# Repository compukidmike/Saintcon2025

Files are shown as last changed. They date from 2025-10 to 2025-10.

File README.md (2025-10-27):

# Saintcon 2025 Badge

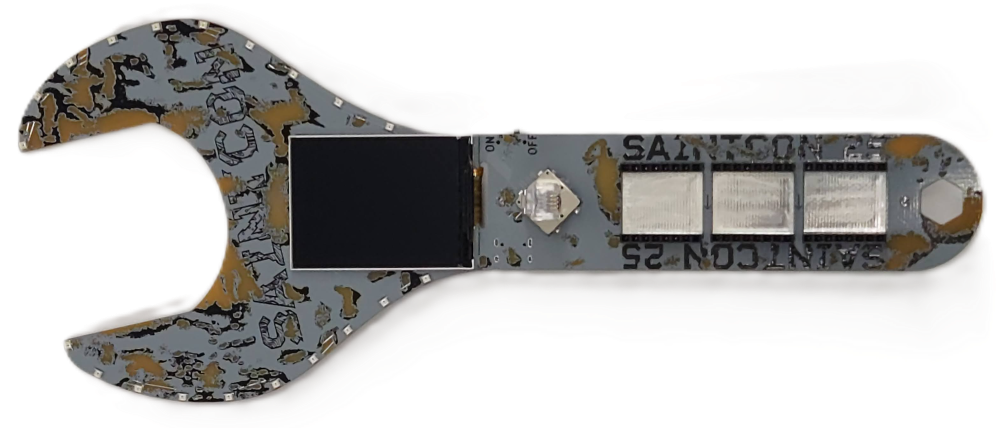
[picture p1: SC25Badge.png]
Saintcon2025 Badge


This year's badge is a comically oversized wrench. In technical terms it's a 50mm (~2in) wrench and the lanyard hole is a 10mm, naturally. It has an NFC tag embedded in the business end which is used for interacting with the badge game hardware. This, of course, involved turning Nuts which were NFC devices that would write one-time codes to the NFC tag in the badge. The badge would then check those codes in with the game server which would either award points or unlock game nodes.

The board files and firmware for the badges and the nuts is included here. If you have any questions or want more info about anything, please let me know!

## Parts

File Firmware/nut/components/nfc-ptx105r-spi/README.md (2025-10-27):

# PTX105R Arduino Library

This NFC library uses the **PTX105R non-OS IOT Reader SDK v7.2.0** for the **SPI** interface.

There are four examples to demonstrate the following functionality:
- Read NDEF message
- Write NDEF message to NDEF-formatted cards
- Emulate a Type 4 tag containing an NDEF message
- Run the SDK's reader demo application, which displays basic card information

Supported RF-technology types: A, B, F, V

Supported tag-protocol types: Type 2, 3, 4, 5

## Board Compatibility

- Arduino UNO R4 MINIMA
- Arduino UNO R4 WiFi

## Shield Compatibility

- WS004-NFCShield-PoCZ PTX105R Arduino Shield Rev A

## Getting Started

Please refer to the [User Manual](https://lpccs-docs.renesas.com/ntpg_apps/ptx105r_arduino_shield/spi/latest/tutorial/index.html) and [Product Page](https://www.renesas.com/en/products/wireless-connectivity/nfc/ptx105r-mid-power-multi-protocol-nfc-forum-compliant-reader/WS031-NFCShld-REFZ-PTX105R-Arduino-Shield-R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) for more information.

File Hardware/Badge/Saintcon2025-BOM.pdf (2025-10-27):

Saintcon2025 Final BOM

Reference | Qty | Value | Footprint
BT1 | 1 | Battery | Battery:BatteryHolder_MPD_BC12AAPC_2xAA
C1,C7,C10 | 3 | 0.1uF | Capacitor_SMD:C_0603_1608Metric
C2,C3,C5,C6,C8,C9,C11,C12,C14 | 9 | 10uF | Capacitor_SMD:C_0603_1608Metric
C4,C19 | 2 | 1uF | Capacitor_SMD:C_0603_1608Metric
C13 | 0 | DNP | Capacitor_SMD:C_0603_1608Metric
D1,D2,D3,D4,D5,D6,D7,D8,D9,D1 0,D11,D12,D13,D14,D15,D16,D17, D18,D19,D20 | 20 | WS2812B-2020 | LED_SMD:LED_WS2812B-2020_PLCC4_2.0x2.0mm
J1 | 1 | USB_C_Receptacle_USB2.0 | Connector_USB:USB_C_Receptacle_XKB_U262-16XN-4BVC11
L1 | 1 | L | Inductors:L_0806_2016
R1,R11 | 2 | 10k | Resistor_SMD:R_0603_1608Metric
R2,R3 | 2 | 5.1k | Resistor_SMD:R_0603_1608Metric
R4 | 1 | 10 | Resistor_SMD:R_0603_1608Metric
R5,R6 | 2 | 1.2k | Resistor_SMD:R_0603_1608Metric
R7,R8 | 2 | 4.7k | Resistor_SMD:R_0603_1608Metric
R9 | 1 | 365 | Resistor_SMD:R_0603_1608Metric
R10 | 1 | 1k | Resistor_SMD:R_0603_1608Metric
SW1 | 1 | SW_SPDT | C&KSlideSwitches:JS202011JAQN
SW2 | 1 | 4-WayW/switch | NavSwitchSMD:2425755-1
U1 | 1 | AZ1117-3.3 | Package_TO_SOT_SMD:SOT-89-3
U2 | 1 | LCD-2_0-ST7789 | LCD_Displays:LCD-2_0-ST7789V-22PIN
U3 | 1 | ATECC608B-SSHDA | Package_SO:SOIC-8_3.9x4.9mm_P1.27mm
U4 | 1 | ESP32-S3-WROOM-1 | Espressif:ESP32-S3-WROOM-1
U5 | 1 | XC9148G33DER-G | Package_USP:USP-6C
U6 | 1 | ST25DV04K-IER6S3 | Package_SO:SO-8_3.9x4.9mm_P1.27mm
U9 | 1 | A3910 | Package_DFN_QFN:DFN-8-1EP_2x2mm_P0.5mm_EP0.9x1.6mm
U10,U11,U13 | 3 | SAINTCON-Minibadge | minibadge_kicad:SAINTCON-Minibadge-Shiny-SmallHoles

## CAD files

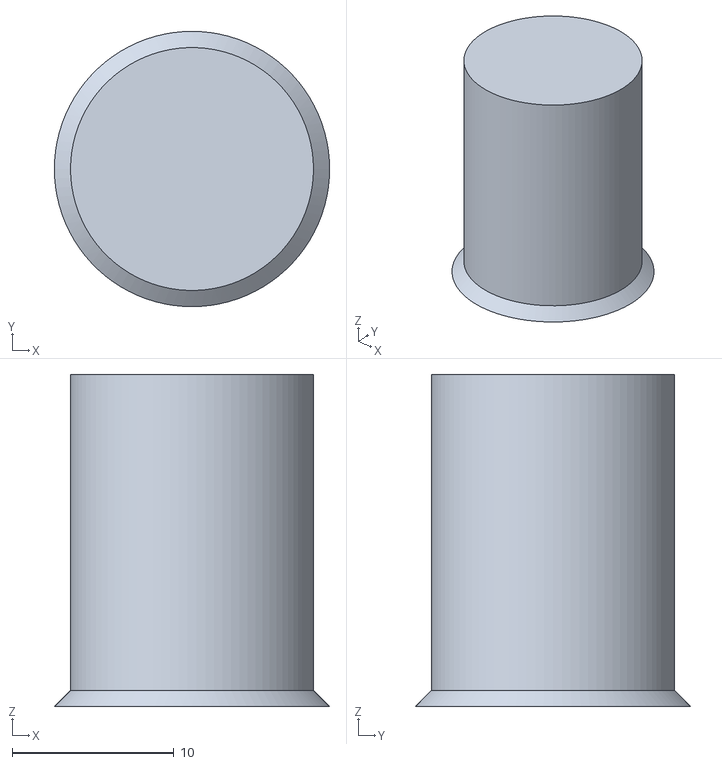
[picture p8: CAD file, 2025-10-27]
Hardware/Nut/3D Prints/Saintcon2025NutButton.stl
17.0 x 17.0 x 20.5

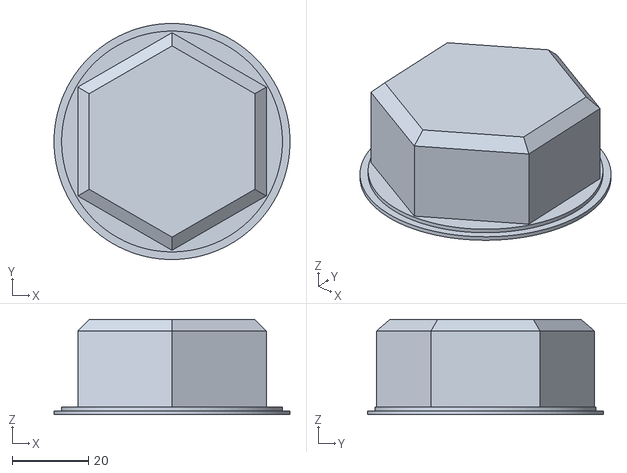
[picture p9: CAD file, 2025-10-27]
Hardware/Nut/3D Prints/Saintcon2025Nut.stl
62.0 x 62.0 x 25.0

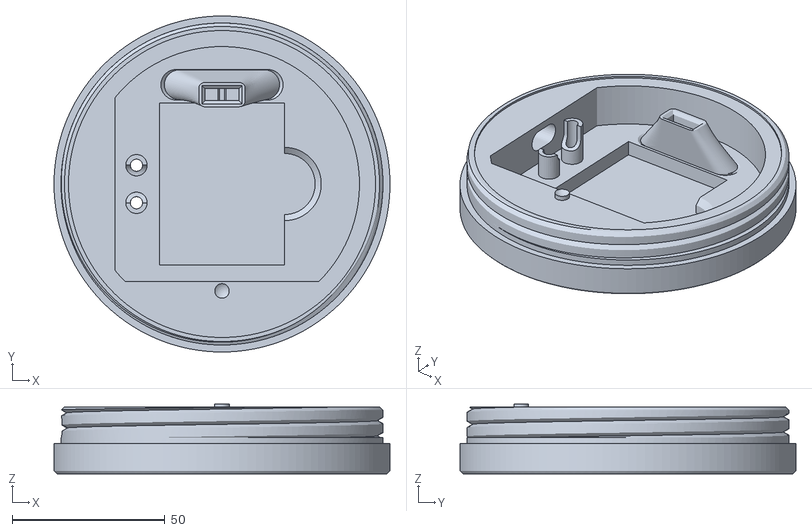
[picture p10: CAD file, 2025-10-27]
Hardware/Nut/3D Prints/Saintcon2025NutBase.stl
110.0 x 110.0 x 22.9

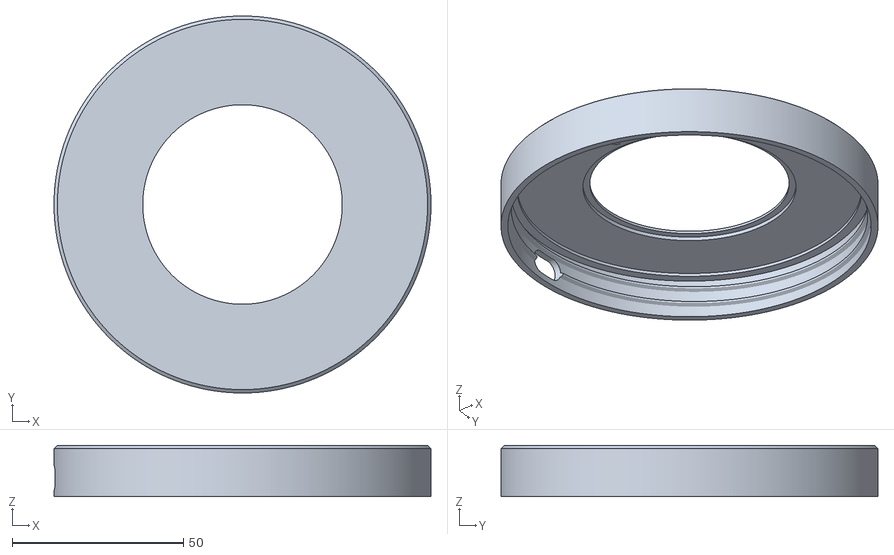
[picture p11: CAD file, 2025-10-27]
Hardware/Nut/3D Prints/Saintcon2025NutRing.stl
110.0 x 110.0 x 15.0

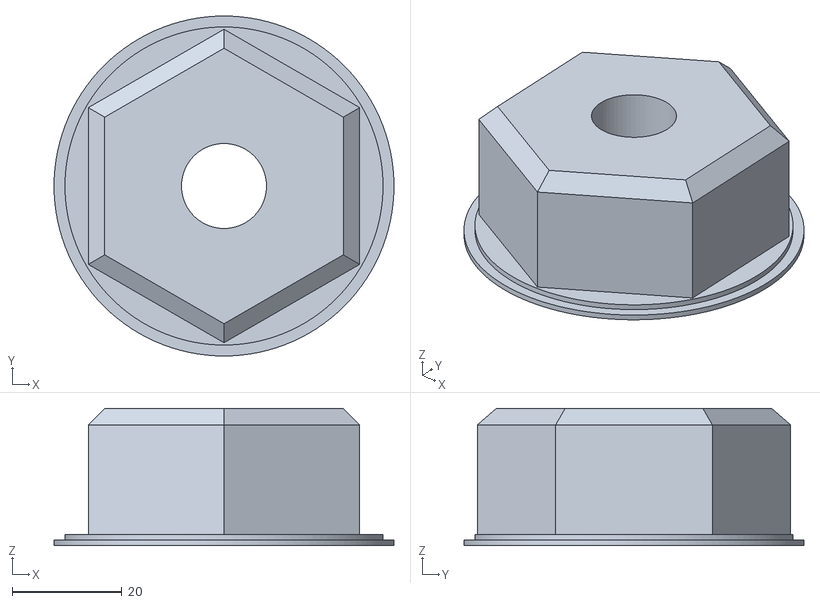
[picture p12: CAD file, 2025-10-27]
Hardware/Nut/3D Prints/Saintcon2025NutWithButtonHole.stl
62.0 x 62.0 x 25.0

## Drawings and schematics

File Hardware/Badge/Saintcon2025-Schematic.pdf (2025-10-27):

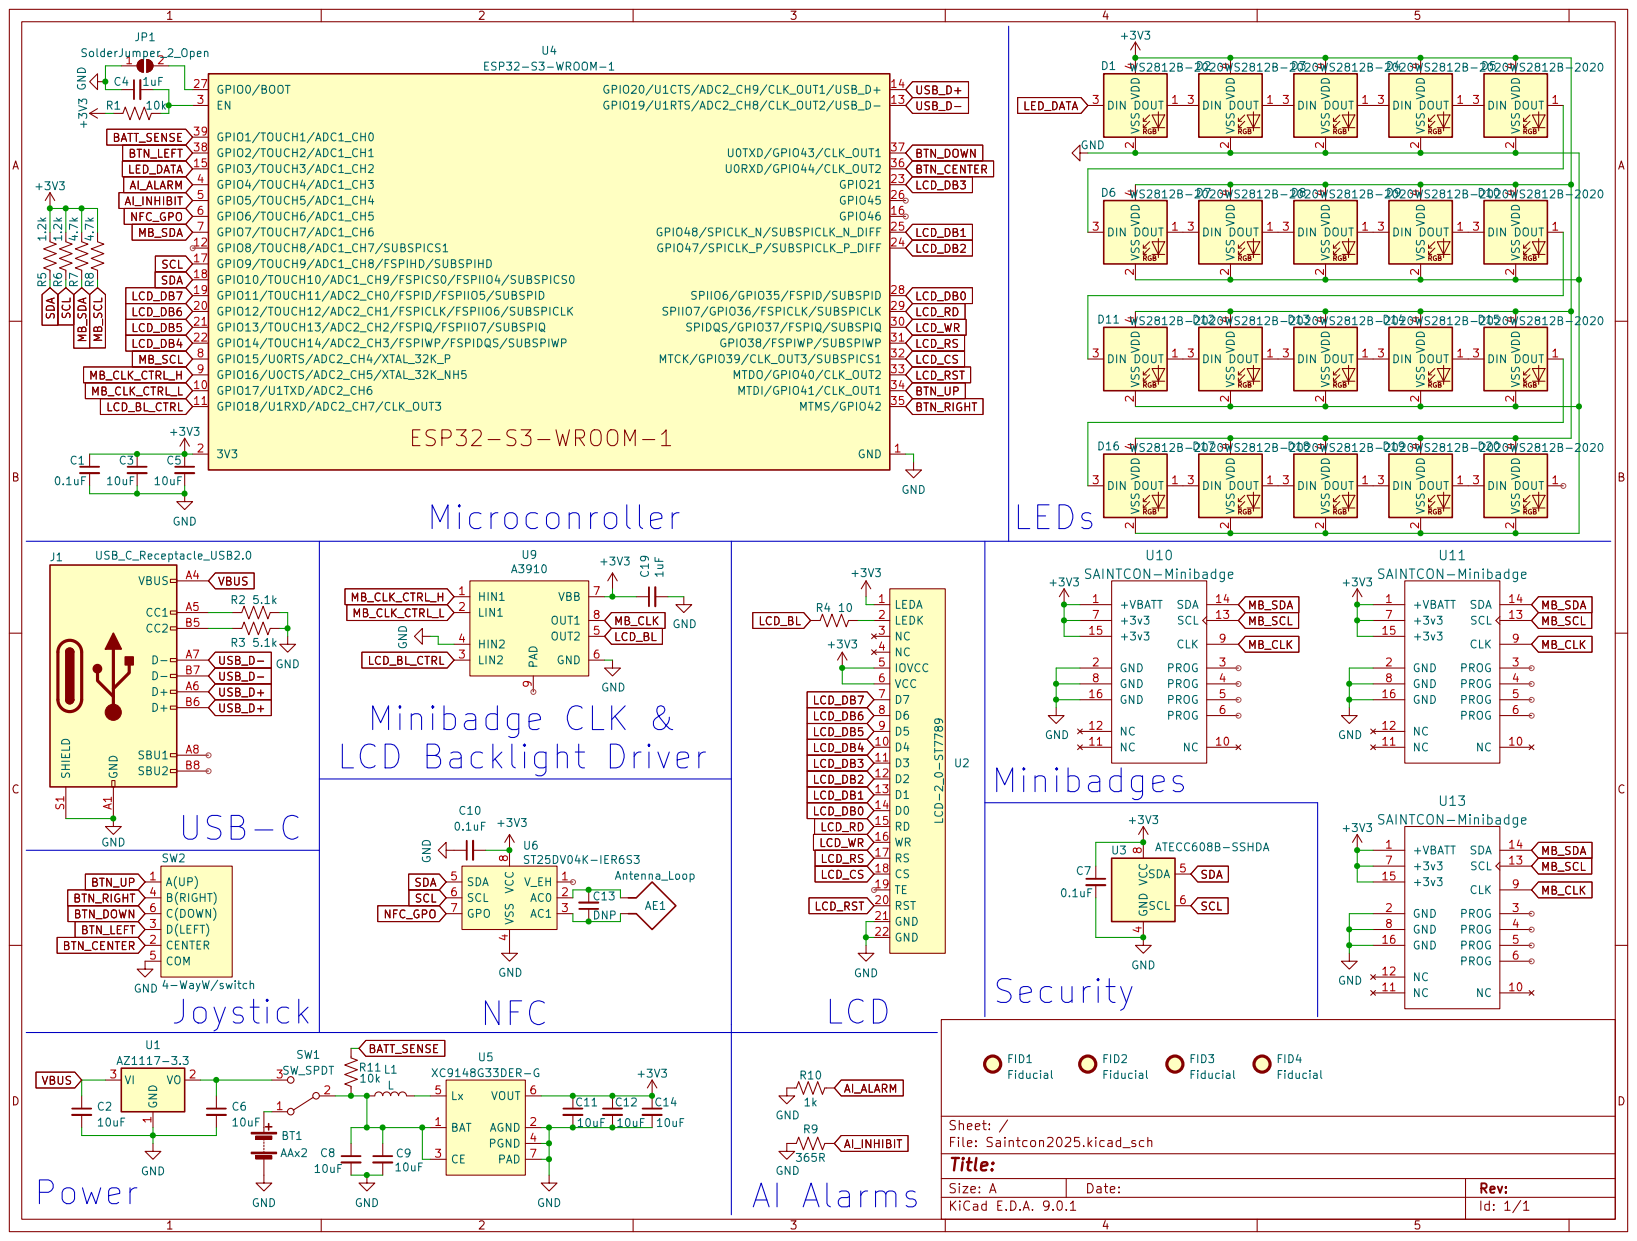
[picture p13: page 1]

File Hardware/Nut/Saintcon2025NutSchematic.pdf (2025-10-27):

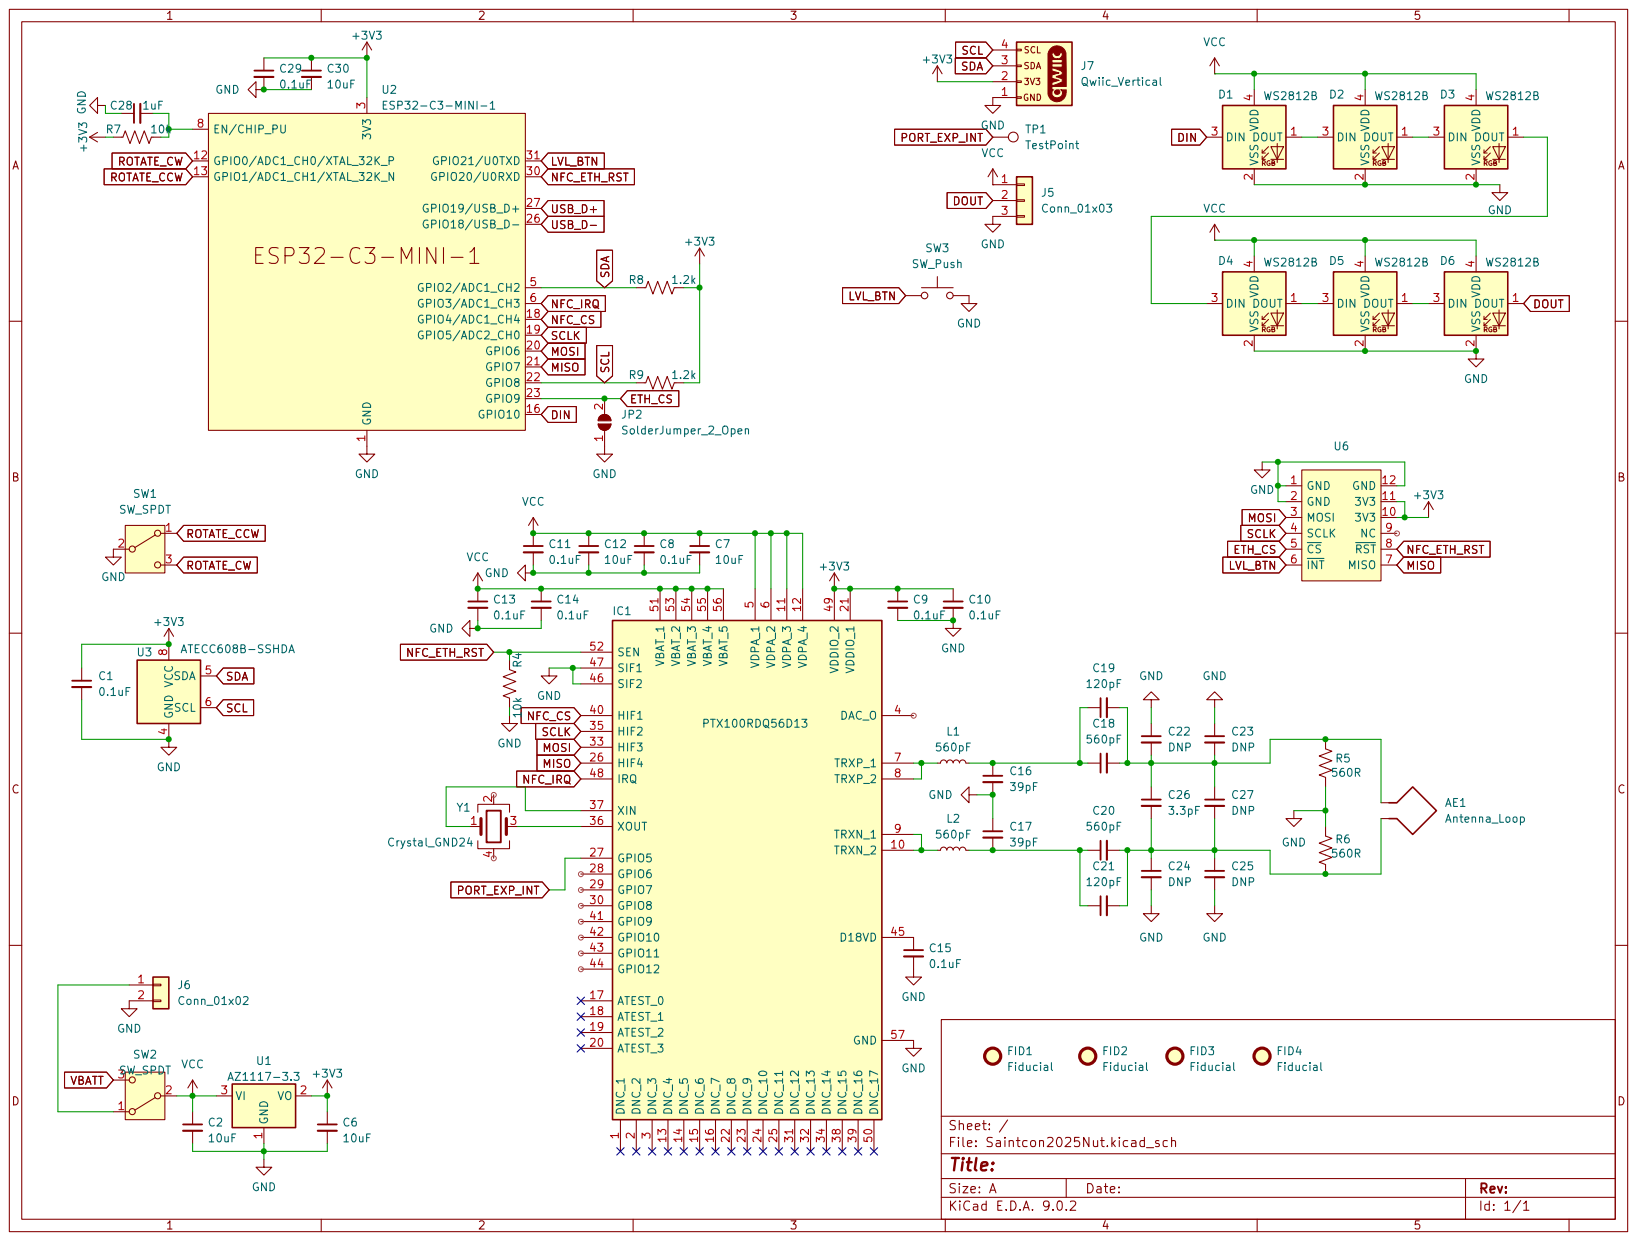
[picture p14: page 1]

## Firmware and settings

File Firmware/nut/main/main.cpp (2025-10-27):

#include "Arduino.h"
#include "driver/gpio.h"
#include "driver/spi_master.h"
#include "esp_err.h"
#include "esp_eth.h"
#include "esp_event.h"
#include "esp_log.h"
#include "esp_netif.h"
#include "esp_timer.h"

#include "ethernet_init.h"

#include "nut.h"
#include "nut/code_manager.h"
#include "i2c_manager.h"
#include "nvs.h"
#include "nvs_flash.h"
#include "secure_element.h"
#include "wifi_manager.h"
#include "network_manager.h"
#include "led.h"
#include "IotReader.h"
#include <Logging.h>
#include "mcp23x17.h"
#include "led_patterns.h"
#include "api.h"

#define CW_PIN      (gpio_num_t)1
#define CCW_PIN     (gpio_num_t)0
#define LEVEL_PIN   (gpio_num_t)21
#define NFC_SEN_PIN (gpio_num_t)20

#define DEBOUNCE_TIME_US       50000   // 50ms
#define ACTIVATION_THRESHOLD   3       // must hit 2 valid activations
#define DOUBLE_PRESS_WINDOW_US 2000000 // 2 seconds

#define LED_COUNT      6
#define FADE_STEPS     30 // Number of fade frames per transition
#define FRAME_DELAY_MS 10 // Delay between fade frames (approx 100Hz update)

#define BUTTON1_I2C_PIN     10
#define BUTTON2_I2C_PIN     11
#define BUTTONLIGHT_I2C_PIN 12

// Struct for ISR -> task events
typedef struct {
    int switch_id;
} switch_event_t;

static QueueHandle_t switch_evt_queue = NULL;

// State tracking for each switch
typedef struct {
    gpio_num_t gpio_num;
    int id;
    int activation_count;
    int64_t last_time_us;
} switch_state_t;

static switch_state_t switches[] = {
    {CW_PIN, 1, 0, 0},
    {CCW_PIN, 2, 0, 0},
};

// Tracks which switch was last activated
static volatile int last_switch_id = -1;

static const char *TAG = "main";

TaskHandle_t nfcTaskHandle;

static led_pattern_t current_pattern;
static SemaphoreHandle_t pattern_mutex;

uint32_t code_level              = 1;
volatile bool code_level_changed = false;

bool doorIsOpen = false;

// lv_timer_t *ledtimer;

void led_update();
void nfcupdate(void);
esp_err_t nfcWriteCode(uint16_t timeout);
void patchPanelUpdate();
void checkPortExpanderIO();
extern "C" void openDoor();
void checkButtons();
void checkInputs();
static void setup_rotation_interrupts(void);

static void leds_off(void);
void led_pattern_set(const led_pattern_t *pattern);
static void fade_in_all(uint32_t red, uint32_t green, uint32_t blue, uint32_t duration_ms);
static void fade_out_all(uint32_t red, uint32_t green, uint32_t blue, uint32_t duration_ms);
static void fade_in_led(int index, uint32_t red, uint32_t green, uint32_t blue, uint32_t duration_ms);
static void run_blink_pattern(const led_pattern_t *p);
static void run_chase_pattern(const led_pattern_t *p);
static void led_task(void *arg);
void led_task_start(void);

static void IRAM_ATTR level_isr_handler(void *arg);

using namespace PtxIotReader;
bool nfcstatus;

// Helper function to log stack usage for a given task
static void log_stack_usage(const char *location, TaskHandle_t task = NULL) {
    if (task == NULL) {
        task = xTaskGetCurrentTaskHandle();
    }

    UBaseType_t high_water_mark = uxTaskGetStackHighWaterMark(task);

    ESP_LOGI(TAG, "[STACK] %s - High water mark: %u bytes free (min remaining)", location, high_water_mark * sizeof(StackType_t));
}

static std::vector<uint8_t> create_text_ndef_record(const char *text) {
    size_t text_len = strlen(text);
    std::vector<uint8_t> record;

    record.push_back(0xD1);
    record.push_back(0x01);
    record.push_back(3 + text_len);
    record.push_back(0x54);
    record.push_back(0x02);
    record.push_back('e');
    record.push_back('n');

    for (size_t i = 0; i < text_len; i++) {
        record.push_back(text[i]);
    }

    return record;
}

/*
If true, the loop will wait until a character is received
over the console, before reading the next card.
If false, the loop will continuously read any card placed
into the field.
*/
const bool readOneByOne = false;

// with 500 ms idle time between cycles
// Low Power Card Detection enabled with regular polling at every 10th cycle
// and stand-by mode enabled
const PollingConfig pollConfig = {
    .pollTypeA     = 1U,
    .pollTypeB     = 1U,
    .pollTypeF212  = 1U,
    .pollTypeV     = 1U,
    .idleTime      = 500U,
    .discoverMode  = 10U,
    .enableStandBy = 1U,
};

static mcp23x17_t mcp23017Dev           = {0};
static mcp23x17_handle_t mcp23017Handle = NULL;

// #define PATCHPANELPIXELSTART 150

// uint8_t patchPanelPixels[6] = {
//   PATCHPANELPIXELSTART,
//   PATCHPANELPIXELSTART+3,
//   PATCHPANELPIXELSTART+5,
//   PATCHPANELPIXELSTART+8,
//   PATCHPANELPIXELSTART+10,
//   PATCHPANELPIXELSTART+13
//   };
//   uint8_t connectedports = 0;
//   uint16_t connections = 0;

#define PATCHPANELPIXELSTART 6

uint8_t patchPanelPixels[6] = {PATCHPANELPIXELSTART,     PATCHPANELPIXELSTART + 3,  PATCHPANELPIXELSTART + 5,
                               PATCHPANELPIXELSTART + 8, PATCHPANELPIXELSTART + 10, PATCHPANELPIXELSTART + 13};
uint8_t connectedports      = 0;
uint16_t connections        = 0;
bool nfc_write_in_progress  = false; // Flag to disable patch panel updates during NFC writes

static void ip_event_handler(void *arg, esp_event_base_t event_base, int32_t event_id, void *event_data) {
    if (event_base == IP_EVENT && event_id == IP_EVENT_ETH_GOT_IP) {
        ip_event_got_ip_t *event           = (ip_event_got_ip_t *)event_data;
        const esp_netif_ip_info_t *ip_info = &event->ip_info;

        ESP_LOGI(TAG, "Ethernet Got IP Address");
        ESP_LOGI(TAG, "~~~~~~~~~~~");
        ESP_LOGI(TAG, "ETHIP:" IPSTR, IP2STR(&ip_info->ip));
        ESP_LOGI(TAG, "ETHMASK:" IPSTR, IP2STR(&ip_info->netmask));
        ESP_LOGI(TAG, "ETHGW:" IPSTR, IP2STR(&ip_info->gw));
        ESP_LOGI(TAG, "~~~~~~~~~~~");
    } else if (event_base == IP_EVENT && event_id == IP_EVENT_ETH_LOST_IP) {
        ESP_LOGI(TAG, "Ethernet Lost IP Address");
    }
}

// void app_main(void) {
extern "C" void app_main() {
    esp_err_t err;
    int64_t start_time = esp_timer_get_time();

    esp_timer_init();

    // Global log level override
    // esp_log_set_level_master(ESP_LOG_DEBUG);
    // esp_log_level_set("*", ESP_LOG_DEBUG);

    // Initialize the NVS storage component
    err = nvs_init();
    if (err != ESP_OK) {
        ESP_LOGE(TAG, "Failed to initialize NVS: %s", esp_err_to_name(err));
        return;
    }

    // vTaskDelay(pdMS_TO_TICKS(1000));

    // Initialize LEDs
    led_init();
    led_gamma_enable(true);
    // // Simple LED Test - remove later
    // led_clear();
    // // ledtimer = lv_timer_create(led_update, 50, 0);
    // for (int x = 0; x < 6; x++) {
    //     led_set(x, 10, 10, 10);
    //     led_show();
    //     vTaskDelay(pdMS_TO_TICKS(100));
    // }
    // for (int x = 0; x < 6; x++) {
    //     led_set(x, 0, 0, 0);
    //     led_show();
    //     vTaskDelay(pdMS_TO_TICKS(100));
    // }

    led_task_start();

    led_pattern_t fade_blink = {
        .type        = LED_PATTERN_CHASE,
        .red         = 255,
        .green       = 255,
        .blue        = 255,
        .on_ms       = 500,
        .off_ms      = 500,
        .blink_count = 0, // blink forever
        .speed_ms    = 50,
        .leds_on     = 1,
        .chase_count = 0,
        .chase_dir   = 0,
        .fade        = false,
    };
    led_pattern_set(&fade_blink);

    // Initialize the default event loop (needed for ethernet)
    err = esp_event_loop_create_default();
    if (err != ESP_OK) {
        ESP_LOGE(TAG, "Failed to create default event loop: %s", esp_err_to_name(err));
        return;
    }

    // Install the ISR service if needed
    err = gpio_install_isr_service(ESP_INTR_FLAG_LOWMED);
    if (err != ESP_OK && err != ESP_ERR_INVALID_STATE) {
        ESP_LOGE(TAG, "Failed to install ISR service: %s", esp_err_to_name(err));
    }

    // Initialize the I2C manager
    err = i2c_manager_init_auto();
    if (err != ESP_OK) {
        ESP_LOGE(TAG, "Failed to initialize I2C manager: %s", esp_err_to_name(err));
        return;
    }

    // Initialize the secure element
    err = se_init();
    if (err != ESP_OK) {
        ESP_LOGE(TAG, "Failed to initialize secure element: %s", esp_err_to_name(err));
        return;
    }

    // Button/Switch Init
    gpio_reset_pin(CW_PIN);
    gpio_set_direction(CW_PIN, GPIO_MODE_INPUT);
    gpio_set_pull_mode(CW_PIN, GPIO_PULLUP_ONLY);
    gpio_reset_pin(CCW_PIN);
    gpio_set_direction(CCW_PIN, GPIO_MODE_INPUT);
    gpio_set_pull_mode(CCW_PIN, GPIO_PULLUP_ONLY);
    gpio_reset_pin(LEVEL_PIN);
    gpio_set_direction(LEVEL_PIN, GPIO_MODE_INPUT);
    gpio_set_pull_mode(LEVEL_PIN, GPIO_PULLUP_ONLY);

    // Register ethernet and IP event handlers
    err = esp_event_handler_register(IP_EVENT, ESP_EVENT_ANY_ID, &ip_event_handler, NULL);
    if (err != ESP_OK) {
        ESP_LOGW(TAG, "Failed to register IP event handler: %s", esp_err_to_name(err));
    }

    // Load existing config first (including any migrations) before making ANY changes
    err = load_nut_config();
    if (err != ESP_OK) {
        ESP_LOGW(TAG, "Loading default nut config due to error");
        nut_config = NUT_DEFAULTS;
    }

    // Detect hardware configuration BEFORE initializing network manager
    // This scans I2C bus for MCP23017 to determine if we have TELECOM hardware
    err = nut_detect_hardware(false);
    if (err != ESP_OK) {
        ESP_LOGE(TAG, "Failed to detect hardware configuration: %s", esp_err_to_name(err));
        return;
    }

    // Determine if we have TELECOM hardware (MCP23017 + W5500)
    bool has_ethernet = (nut_config.hw_type == NUT_HW_TYPE_TELECOM);

    // Initialize the network manager with correct hardware configuration
    network_manager_config_t nm_config = {
        .enable_wifi                = true,         // Always enable WiFi
        .enable_ethernet            = has_ethernet, // Only enable Ethernet on TELECOM hardware
        .ethernet_fallback_to_wifi  = true,         // Use WiFi if Ethernet fails
        .wifi_fallback_to_ethernet  = true,         // Keep trying Ethernet even after WiFi connects
        .ethernet_retry_interval_ms = 30000,        // Retry Ethernet every 30 seconds
    };
    ESP_LOGI(TAG, "Initializing network manager (WiFi=%d, Ethernet=%d)", nm_config.enable_wifi, nm_config.enable_ethernet);
    err = network_manager_init(&nm_config);
    if (err != ESP_OK) {
        ESP_LOGE(TAG, "Failed to initialize network manager: %s", esp_err_to_name(err));
        return;
    }

    // Quiet noisy W5500 driver debug logs
    esp_log_level_set("w5500.mac", ESP_LOG_WARN);

    // Initialize the nut (this will register a callback with network_manager)
    err = nut_init();
    if (err != ESP_OK) {
        ESP_LOGE(TAG, "Failed to initialize nut component: %s", esp_err_to_name(err));
        return;
    }

    switch_evt_queue = xQueueCreate(10, sizeof(switch_event_t));
    switch_event_t evt;

    // Defer rotation interrupt setup to a separate task to allow other init to proceed
    auto rotation_init_task_fn = [](void *arg) __attribute__((used)) {
        const TickType_t check_delay = pdMS_TO_TICKS(200);
        for (;;) {
            if (code_mgr_is_ready()) {
                break;
            }
            vTaskDelay(check_delay);
        }
        setup_rotation_interrupts();
        vTaskDelete(NULL);
    };
    BaseType_t r = xTaskCreate((TaskFunction_t)rotation_init_task_fn, "rotation_init", 2048, NULL, 5, NULL);
    if (r != pdPASS) {
        ESP_LOGW(TAG, "Failed to create rotation init task; enabling interrupts immediately");
        setup_rotation_interrupts();
    }

    // Initialize LEDs
    // led_init();
    // // Simple LED Test - remove later
    // led_clear();
    // // ledtimer = lv_timer_create(led_update, 50, 0);
    // for (int x = 0; x < 6; x++) {
    //     led_set(x, 10, 10, 10);
    //     led_show();
    //     vTaskDelay(pdMS_TO_TICKS(100));
    // }
    // for (int x = 0; x < 6; x++) {
    //     led_set(x, 0, 0, 0);
    //     led_show();
    //     vTaskDelay(pdMS_TO_TICKS(100));
    // }

    // Enable NFC Chip
    gpio_reset_pin((gpio_num_t)20);
    gpio_set_direction((gpio_num_t)20, GPIO_MODE_OUTPUT);
    gpio_set_level((gpio_num_t)20, 1);

    // Initialize MCP23017 if we have TELECOM hardware
    if (has_ethernet) {
        ESP_LOGI(TAG, "Initializing MCP23017 I/O expander...");
        err = mcp23x17_init_desc(&mcp23017Dev, 0x20, I2C_NUM_0, &mcp23017Handle);
        if (err != ESP_OK) {
            ESP_LOGE(TAG, "Failed to initialize MCP23017: %s", esp_err_to_name(err));
            return;
        }
        ESP_LOGI(TAG, "MCP23017 initialized successfully");
        mcp23x17_port_set_mode(&mcp23017Dev, 0xFFFF); // Set all as inputs
        for (int x = 0; x < 8; x++) {
            mcp23x17_set_pullup(&mcp23017Dev, x, true); // Enable pullups on pins 0-7
        }
        mcp23x17_set_pullup(&mcp23017Dev, 8, true); // Latch Sensor
        mcp23x17_set_level(&mcp23017Dev, 9, 0);
        mcp23x17_set_mode(&mcp23017Dev, 9, MCP23X17_GPIO_OUTPUT); // Latch Solenoid
        mcp23x17_set_level(&mcp23017Dev, 9, 0);
        mcp23x17_set_mode(&mcp23017Dev, BUTTON1_I2C_PIN, MCP23X17_GPIO_INPUT);
        mcp23x17_set_pullup(&mcp23017Dev, BUTTON1_I2C_PIN, true);
        mcp23x17_set_mode(&mcp23017Dev, BUTTON2_I2C_PIN, MCP23X17_GPIO_INPUT);
        mcp23x17_set_pullup(&mcp23017Dev, BUTTON2_I2C_PIN, true);
        mcp23x17_set_mode(&mcp23017Dev, BUTTONLIGHT_I2C_PIN, MCP23X17_GPIO_OUTPUT);
        mcp23x17_set_level(&mcp23017Dev, BUTTONLIGHT_I2C_PIN, 0);
    }

    // Initialize ethernet if we have TELECOM hardware (MCP23017 + W5500)
    if (has_ethernet) {
        ESP_LOGI(TAG, "TELECOM hardware detected - ethernet initialization temporarily disabled for testing");

        esp_netif_init();
        esp_netif_config_t cfg = ESP_NETIF_DEFAULT_ETH();
        esp_netif_t *eth_netif = esp_netif_new(&cfg);
        assert(eth_netif);

        // Initialize all configured ethernet interfaces (W5500)
        esp_eth_handle_t *eth_handles = NULL;
        uint8_t eth_cnt               = 0;
        err                           = ethernet_init_all(&eth_handles, &eth_cnt);
        if (err == ESP_OK && eth_cnt > 0) {
            ESP_LOGI(TAG, "Ethernet initialized successfully (%d interface%s)", eth_cnt, eth_cnt > 1 ? "s" : "");

            // Start the ethernet interface(s)
            for (uint8_t i = 0; i < eth_cnt; i++) {
                esp_netif_attach(eth_netif, esp_eth_new_netif_glue(eth_handles[i]));
                err = esp_eth_start(eth_handles[i]);
                if (err == ESP_OK) {
                    ESP_LOGI(TAG, "Ethernet interface %d started", i);

                    // Get the netif handle and start DHCP client
                    esp_netif_t *eth_netif = esp_netif_get_default_netif(); // esp_netif_get_handle_from_ifkey("ETH_DEF");
                    if (eth_netif) {
                        err = esp_netif_dhcpc_start(eth_netif);
                        if (err == ESP_OK) {
                            ESP_LOGI(TAG, "DHCP client started for ethernet interface %d", i);
                        } else if (err == ESP_ERR_ESP_NETIF_DHCP_ALREADY_STARTED) {
                            ESP_LOGI(TAG, "DHCP client already running for ethernet interface %d", i);
                        } else {
                            ESP_LOGW(TAG, "Failed to start DHCP client for ethernet interface %d: %s", i, esp_err_to_name(err));
                        }
                    } else {
                        ESP_LOGW(TAG, "Failed to get netif handle for ethernet interface %d", i);
                    }
                } else {
                    ESP_LOGW(TAG, "Failed to start ethernet interface %d: %s", i, esp_err_to_name(err));
                }
            }
        } else {
            ESP_LOGW(TAG, "Failed to initialize ethernet: %s", esp_err_to_name(err));
        }
    } else {
        ESP_LOGI(TAG, "WIRELESS hardware detected - doing SPI2 initialization for NFC");

        // Initialize SPI bus
        ESP_LOGI(TAG, "Initializing SPI2 bus for NFC...");
        spi_bus_config_t buscfg = {
            .mosi_io_num     = 6,
            .miso_io_num     = 7,
            .sclk_io_num     = 5,
            .quadwp_io_num   = -1,
            .quadhd_io_num   = -1,
            .max_transfer_sz = 4096,
        };
        err = spi_bus_initialize(SPI2_HOST, &buscfg, SPI_DMA_CH_AUTO);
        if (err != ESP_OK) {
            ESP_LOGE(TAG, "Failed to initialize SPI2 bus: %s", esp_err_to_name(err));
            return;
        }
        ESP_LOGI(TAG, "SPI2 bus initialized successfully");
    }

    Serial.begin(115200);
    // while (!Serial)
    //     ; // wait for the port to be opened
    ESP_LOGI(TAG, "Starting NFC Reader...");

    // Retry NFC initialization up to 3 times
    int nfc_retry_count       = 0;
    const int max_nfc_retries = 65535;
    nfcstatus                 = false;

    while (!nfcstatus && nfc_retry_count < max_nfc_retries) {
        nfc_retry_count++;
        ESP_LOGI(TAG, "NFC initialization attempt %d/%d", nfc_retry_count, max_nfc_retries);

        // initialize the reader instance
        nfcstatus = IotReader::getReader().begin();

        if (!nfcstatus) {
            ESP_LOGW(TAG, "NFC initialization attempt %d failed", nfc_retry_count);
            if (nfc_retry_count < max_nfc_retries) {
                ESP_LOGI(TAG, "Waiting 2 seconds before retry...");
                vTaskDelay(pdMS_TO_TICKS(2000));
            }
        }
    }

    if (!nfcstatus) {
        ESP_LOGE(TAG, "ERROR: Failed to initialize NFC reader after %d attempts", max_nfc_retries);
    } else {
        ESP_LOGI(TAG, "NFC Reader Started successfully on attempt %d", nfc_retry_count);
        bool status = IotReader::getReader().pollingStop();
        if (!status) {
            ESP_LOGE(TAG, "ERROR: failed to disable nfc polling.", NULL);
        }
    }

    Serial.println("Place a card on the antenna to read it.");
    Serial.println();

    // int ledcounter = 0;
    // fade_blink.type        = LED_PATTERN_BLINK;
    // fade_blink.blink_count = 1;
    // fade_blink.on_ms       = 1000;
    // fade_blink.off_ms      = 1000;
    // fade_blink.fade        = true;
    // fade_blink.red         = 0;
    // fade_blink.green       = 255;
    // fade_blink.blue        = 0;
    // led_pattern_set(&fade_blink);
    // fade_blink.type = LED_PATTERN_NONE;
    // fade_blink.blink_count = 1;
    // led_pattern_set(&fade_blink);

    // Stack monitoring - log every 30 seconds
    static uint32_t last_stack_log_time  = 0;
    const uint32_t STACK_LOG_INTERVAL_MS = 30000;

    while (1) {
        // Periodic stack usage logging
        uint32_t now = millis();
        if (now - last_stack_log_time >= STACK_LOG_INTERVAL_MS) {
            log_stack_usage("Main loop - periodic check");
            last_stack_log_time = now;
        }

        // led_set(ledcounter, 10,10,10);
        // if(ledcounter > 0) led_set(ledcounter-1, 0,0,0); else led_set(5, 0,0,0);
        // ledcounter ++;
        // if(ledcounter > 5) ledcounter = 0;
        // led_show();

        // nfcupdate(); // Check for NFC tag
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

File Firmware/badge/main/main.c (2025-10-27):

#include "driver/gpio.h"
#include "esp_err.h"
#include "esp_log.h"
#include "esp_timer.h"

#include "badge.h"
#include "battery.h"
#include "dawn_accord.h"
#include "display.h"
#include "i2c_manager.h"
#include "ops_nfc.h"
#include "minibadge.h"
#include "nvs.h"
#include "secure_element.h"
#include "ui.h"
#include "wifi_manager.h"
#include "led.h"

#include "cryptoauthlib.h"
#include <math.h>

#ifndef M_PI
    #define M_PI 3.14159265358979323846
#endif

static const char *TAG = "main";

#ifndef BOOT_PROGRESS_MAX_BRIGHTNESS
    #define BOOT_PROGRESS_MAX_BRIGHTNESS 40
#endif
#ifndef BOOT_PROGRESS_HOLD_MS
    #define BOOT_PROGRESS_HOLD_MS 150
#endif
#ifndef BOOT_PROGRESS_FALLBACK_TOL_MS
    #define BOOT_PROGRESS_FALLBACK_TOL_MS 250
#endif

// -------------------------------------------------------------------------------------------------
// Boot Progress (Mirrored Bottom-Up Gradient: red -> yellow -> green)
// -------------------------------------------------------------------------------------------------
typedef struct {
    uint32_t total_steps;   // total boot progress steps
    uint32_t current_step;  // completed steps
    bool done;              // reached 100%
    uint32_t hold_ms;       // how long to hold before clearing
    uint64_t done_start_ms; // timestamp when we first hit 100%
    bool fading;
    uint64_t fade_start_ms;
    uint32_t fade_duration_ms;
} boot_progress_state_t;

static boot_progress_state_t boot_progress = {
    .total_steps      = 10,
    .current_step     = 0,
    .done             = false,
    .hold_ms          = BOOT_PROGRESS_HOLD_MS,
    .done_start_ms    = 0,
    .fading           = false,
    .fade_start_ms    = 0,
    .fade_duration_ms = 350,
};
static int boot_progress_layer = -1;

static void boot_progress_destroy_now() {
    if (boot_progress_layer >= 0) {
        int h               = boot_progress_layer;
        boot_progress_layer = -1;
        led_layer_destroy(h);
    }
}

static void boot_progress_start_fade(uint64_t now_ms) {
    if (boot_progress_layer < 0) {
        return;
    }
    if (!boot_progress.fading) {
        boot_progress.fading        = true;
        boot_progress.fade_start_ms = now_ms;
        led_layer_request_refresh();
    }
}

/**
 * @brief Boot-time deferred tasks to be run once the main screen is visible
 */
void badge_boot_deferred_tasks() {
    uint64_t now_ms = esp_timer_get_time() / 1000ULL;
    boot_progress_start_fade(now_ms);
}

static inline void boot_progress_set_total(uint32_t total) {
    if (total == 0) {
        total = 1;
    }
    boot_progress.total_steps = total;
    if (boot_progress.current_step > boot_progress.total_steps) {
        boot_progress.current_step = boot_progress.total_steps;
    }
}
static inline void boot_progress_step() {
    if (boot_progress.current_step < boot_progress.total_steps) {
        boot_progress.current_step++;
        if (boot_progress.current_step >= boot_progress.total_steps && !boot_progress.done) {
            boot_progress.done          = true;
            boot_progress.done_start_ms = esp_timer_get_time() / 1000ULL;
        }
        ESP_LOGD(TAG, "Boot progress step %u/%u", boot_progress.current_step, boot_progress.total_steps);
        led_layer_request_refresh();
    }
}
static void boot_progress_render(uint32_t now_ms, void *user_ctx) {
    (void)user_ctx;
    float ratio = (float)boot_progress.current_step / (float)boot_progress.total_steps;
    if (ratio >= 1.0f) {
        ratio = 1.0f;
        if (!boot_progress.done) {
            boot_progress.done          = true;
            boot_progress.done_start_ms = now_ms;
        }
    }
    const int levels = 10; // 10 vertical levels per side
    float filled     = ratio * levels;
    int full_levels  = (int)filled;
    float partial    = filled - full_levels;
    if (full_levels > levels) {
        full_levels = levels;
    }

    for (int lvl = 0; lvl < levels; lvl++) {
        // Color gradient from red (bottom) to green (top)
        float t = (float)lvl / (float)(levels - 1);
        uint8_t r, g, b;
        if (t < 0.5f) {
            float k = t / 0.5f;
            r       = 255;
            g       = (uint8_t)(k * 255.0f + 0.5f);
            b       = 0;
        } else {
            float k = (t - 0.5f) / 0.5f;
            r       = (uint8_t)((1.0f - k) * 255.0f + 0.5f);
            g       = 255;
            b       = 0;
        }

        float fill;
        if (lvl < full_levels) {
            fill = 1.0f;
        } else if (lvl == full_levels && full_levels < levels) {
            fill = partial;
        } else {
            fill = 0.0f;
        }

        float fade_factor = 1.0f;
        if (boot_progress.fading) {
            uint32_t fade_elapsed = (uint32_t)(now_ms - boot_progress.fade_start_ms);
            if (fade_elapsed >= boot_progress.fade_duration_ms) {
                fade_factor = 0.0f;
            } else {
                float t = (float)fade_elapsed / (float)boot_progress.fade_duration_ms; // 0..1
                // Smooth ease (accelerate end) using cosine: f = (1 - cos(pi * t)) / 2 then invert for fade-out
                float ease  = (1.0f - cosf((float)M_PI * t)) * 0.5f; // 0..1
                fade_factor = 1.0f - ease;
            }
        }
        uint8_t brightness = (uint8_t)(fill * (float)BOOT_PROGRESS_MAX_BRIGHTNESS * fade_factor);

        int left_index  = 9 - lvl;  // invert for left side physical mapping
        int right_index = 10 + lvl; // direct ascending for right side
        if (left_index >= 0 && left_index < NUM_LEDS) {
            led_set_with_brightness(left_index, r, g, b, brightness);
        }
        if (right_index >= 0 && right_index < NUM_LEDS) {
            led_set_with_brightness(right_index, r, g, b, brightness);
        }
    }

    if (boot_progress.fading) {
        uint32_t fade_elapsed = (uint32_t)(now_ms - boot_progress.fade_start_ms);
        if (fade_elapsed >= boot_progress.fade_duration_ms) {
            boot_progress_destroy_now();
            return;
        } else {
            led_layer_request_refresh();
        }
    }
}

void battery_monitor_task(void *pvParameters);
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

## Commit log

2025-10-27 Initial Code Commit
    [Saintcon2025Nut.stl, Saintcon2025NutBase.stl, Saintcon2025NutButton.stl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]
2025-11-12 add AfterCon code for Nut
